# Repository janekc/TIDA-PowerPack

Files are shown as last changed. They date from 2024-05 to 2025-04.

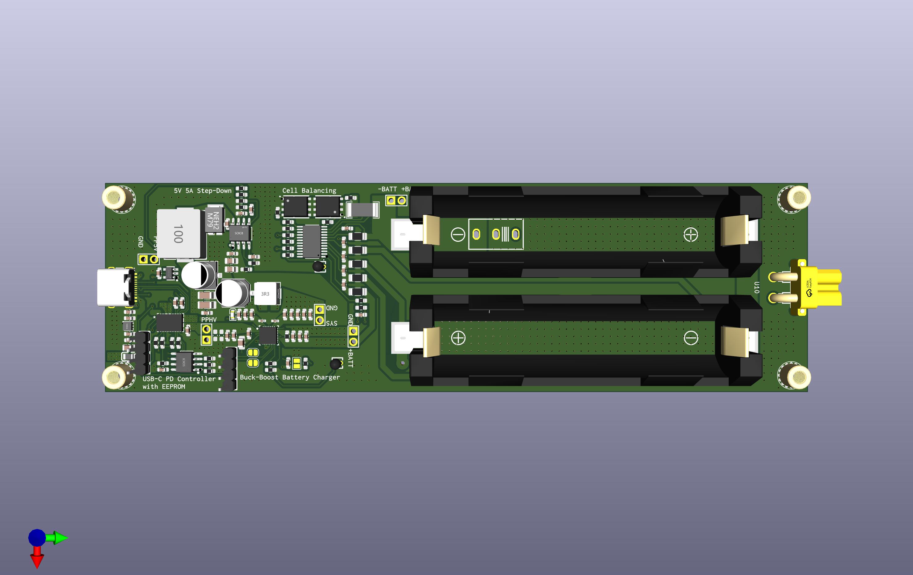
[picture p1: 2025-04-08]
TIDA-PowerPack.jpg

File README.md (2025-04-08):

# TIDA-PowerPack
This board is designed as a prototype for powering your projects using four 18650 lithium-ion battery cells. It delivers a 5V output with a maximum current of 5A. The cells are configured in a 4S1P (4-series, 1-parallel) arrangement, balanced and charged via USB-C Power Delivery (PD) with the maximum charging current supported by the cells.
This design is based on the [TIDA-050047](https://www.ti.com/tool/TIDA-050047#design-products) reference design by Texas Instruments.

TIDA-PowerPack

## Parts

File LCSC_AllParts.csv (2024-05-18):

LCSC Part Number | Manufacture Part Number | Manufacturer | Customer NO. | Package | Description | RoHS | Order Qty. | Min\Mult Order Qty. | Unit Price | Order Price | Type | Value | Rating
C2992604 | XT220UF10V90RV0073 | KNSCHA |  | SMD,D6.3xL5.4mm | 220uF 10V 95mA@120Hz ±20% SMD,D6.3xL5.4mm Aluminum Electrolytic Capacitors - SMD | YES | 40 | 20\20 | 0.039500 | 1.58 | Capacitor | 220uF | 10V
C597194 | 06035C104K4Z2A | Kyocera AVX |  | 0603 | 50V 100nF X7R ±10% 0603 Multilayer Ceramic Capacitors MLCC - SMD/SMT | YES | 250 | 50\50 | 0.020200 | 5.05 | Capacitor | 100nF(0.1uF) | 50V
C729457 | C0603X5R106K250NT | SANYEAR |  | 0603 | 25V 10uF ±10% 0603 Multilayer Ceramic Capacitors MLCC - SMD/SMT | YES | 100 | 10\10 | 0.060100 | 6.01 | Capacitor | 10uF | 25V
C1588 | CL10B102KB8NNNC | Samsung Electro-Mechanics |  | 0603 | 50V 1nF X7R ±10% 0603 Multilayer Ceramic Capacitors MLCC - SMD/SMT | YES | 400 | 100\100 | 0.003300 | 1.32 | Capacitor | 1nF | 50V
C2843785 | XL-5050RGBC-WS2812B | XINGLIGHT |  | SMD5050 | Positive post -30℃~+70℃ RGB 120° SMD5050 Light Emitting Diodes (LED) | YES | 180 | 10\10 | 0.052800 | 9.50 | Diode
C22962 | 0603WAF2200T5E | UNI-ROYAL(Uniroyal Elec) |  | 0603 | 100mW Thick Film Resistors ±100ppm/℃ ±1% 220Ω 0603 Chip Resistor - Surface Mount | YES | 400 | 100\100 | 0.001400 | 0.56 | Resistor | 220Ω | 100mW
C25804 | 0603WAF1002T5E | UNI-ROYAL(Uniroyal Elec) |  | 0603 | 100mW Thick Film Resistors ±100ppm/℃ ±1% 10000Ω 0603 Chip Resistor - Surface Mount | YES | 400 | 100\100 | 0.001100 | 0.44 | Resistor | 10kΩ | 100mW
C318893 | TS-1185EC-C-D-B | XKB Connectivity |  | SMD | No NO 50mA 100000 Times 260gf 12V Brick nogging SPST SMD Tactile Switches | YES | 40 | 10\10 | 0.059500 | 2.38 | Switch
C701341 | ESP32-WROOM-32E-N4 | Espressif Systems |  | SMD,18x25.5mm | SMD,18x25.5mm WiFi Modules | YES | 3 | 1\1 | 3.437100 | 10.31 | Microcontroller
C269429 | RMC0603621%N | TyoHM |  | 0603 | 100mW 1% 62Ω 0603 Chip Resistor - Surface Mount | YES | 100 | 50\50 | 0.004600 | 0.46 | Resistor | 62Ω | 100mW
C6568 | CP2102-GMR | SILICON LABS |  | WQFN-28-EP(5x5) | 1Mbps Transceiver USB WQFN-28-EP(5x5) USB ICs | YES | 3 | 1\1 | 2.737400 | 8.21 | IC
C319148 | U262-161N-4BVC11 | XKB Connectivity |  | SMD | 3A USB 3.1 1 260℃ Surface Mount 16P Female -40℃~+85℃ Gold Copper Alloy Type-C SMD USB Connectors | YES | 7 | 1\1 | 0.373300 | 2.61 | USB-C Port
C5400 | BL1117-33CX | BL(Shanghai Belling) |  | SOT-223 | 1A 60dB@(120Hz) Fixed 3.3V Positive 12V SOT-223 Linear Voltage Regulators (LDO) | YES | 30 | 10\10 | 0.089000 | 2.67 | IC
C62892 | UMH3N | Jiangsu Changjing Electronics Technology Co., Ltd. |  | SC-70-6(SOT-363) | 2 NPN - Pre-Biased 150mW 100mA 50V SC-70-6(SOT-363) Digital Transistors | YES | 60 | 10\10 | 0.052000 | 3.12 | Transistor
C507218 | SN74AHCT32QPWRQ1 | Texas Instruments |  | TSSOP-14 | 2uA 4.5V~5.5V 4 7.9ns@5V,50pF ORGate TSSOP-14 Gates | YES | 10 | 1\1 | 0.314800 | 3.15 | IC
C269696 | RMC06035.1K5%N | TyoHM |  | 0603 | 100mW 5% 5.1kΩ 0603 Chip Resistor - Surface Mount | YES | 300 | 100\100 | 0.002700 | 0.81 | Resistor | 5.1kΩ | 100mW
C2988620 | BH-18650-B1BA002 | MYOUNG |  | SMD | Battery case 18650 SMD Battery Connectors | YES | 8 | 1\1 | 1.431800 | 11.45 | Battery Case
C382139 | TP4056 | TPOWER |  | ESOP-8 | ESOP-8 Battery Management ICs | YES | 5 | 5\5 | 0.159700 | 0.80 | IC
C351410 | DW01A | PUOLOP |  | SOT-23-6L | SOT-23-6L Battery Management ICs | YES | 10 | 20\20 | 0.064600 | 0.65 | IC
C908265 | FS8205A | FUXINSEMI |  | SOT-23-6L | 20V 6A 18mΩ@4.5V,6A 1.5W 2 N-Channel SOT-23-6L MOSFETs | YES | 10 | 10\10 | 0.063800 | 0.64 | Transistor
C115325 | RS-03K1001FT | FH (Guangdong Fenghua Advanced Tech) |  | 0603 | 100mW ±100ppm/℃ ±1% 1kΩ 0603 Chip Resistor - Surface Mount | YES | 200 | 100\100 | 0.001200 | 0.24 | Resistor | 1kΩ | 100mW
C2889393 | 0603 ±5% 100Ω | VO |  | 0603 | 100mW Thick Film Resistors ±100ppm/℃ ±5% 100Ω 0603 Chip Resistor - Surface Mount | YES | 100 | 100\100 | 0.001800 | 0.18 | Resistor | 100Ω | 100mW
C269699 | RMC0603100K1%N | TyoHM |  | 0603 | 100mW 1% 100kΩ 0603 Chip Resistor - Surface Mount | YES | 100 | 100\100 | 0.003800 | 0.38 | Resistor | 100kΩ | 100mW
C19702 | CL10A106KP8NNNC | Samsung Electro-Mechanics |  | 0603 | 10V 10uF X5R ±10% 0603 Multilayer Ceramic Capacitors MLCC - SMD/SMT | YES | 50 | 100\100 | 0.007000 | 0.35 | Capacitor | 10uF | 10V
C72044 | 19-217/R6C-AL1M2VY/3T | Everlight Elec |  | 0603 | -40℃~+85℃ 617.5nm Red 120° 60mW 0603 Light Emitting Diodes (LED) | YES | 50 | 50\50 | 0.017400 | 0.87 | Diode
C193901 | NCD0603C2 | Foshan NationStar Optoelectronics |  | 0603 | Colorless transparence 17mcd~40mcd 565nm~578nm -30℃~+85℃ Green-yellow 130° 65mW 0603 Light Emitting Diodes (LED) | YES | 40 | 20\20 | 0.025500 | 1.02 | Diode
C269421 | RMC06032K1%N | TyoHM |  | 0603 | 100mW 1% 2kΩ 0603 Chip Resistor - Surface Mount | YES | 100 | 100\100 | 0.004100 | 0.41 | Resistor | 2kΩ | 100mW
C605444 | RU20P7C | INJOINIC |  | SOT-23-3L | SOT-23-3L MOSFETs | YES | 10 | 5\5 | 0.111700 | 1.12 | Transistor
C402889 | ERJ3EKF1133V | PANASONIC |  | 0603 | 100mW Thick Film Resistors ±100ppm/℃ ±1% 113000Ω 0603 Chip Resistor - Surface Mount | YES | 50 | 50\50 | 0.006100 | 0.31 | Resistor | 113kΩ | 100mW
C2847559 | MDA1050-2R2M | KOHERelec |  | SMD,10x11mm | 19.5A 2.2uH ±20% 20A 5.1mΩ SMD,10x11mm Inductors (SMD) | YES | 7 | 1\1 | 0.975300 | 6.83 | Coil | 2.2uH | 19.5A
C525386 | TCTR0805F100KF4000T | RESI |  | 0805 | 100kΩ 130mW ±1% 4000K ±1% 0805 NTC Thermistors | YES | 20 | 5\5 | 0.113900 | 2.28 | Resistor | 100kΩ | 130mW
C5139726 | RAT038202FTP | RALEC |  | 0603 | ±1% 82kΩ 0603 Chip Resistor - Surface Mount | YES | 50 | 50\50 | 0.002500 | 0.13 | Resistor | 82kΩ | 100mW
C2915632 | SMTSO3015CTJ | Sinhoo |  | - | - SMD round nut | YES | 50 | 5\5 | 0.050400 | 2.52 | SMD Nut
C123705 | CS1E102M-CRI13 | ST(Semtech) |  | SMD,D12.5xL13.5mm | 1000uF 25V ±20% SMD,D12.5xL13.5mm Aluminum Electrolytic Capacitors - SMD | YES | 10 | 1\1 | 0.202100 | 2.02 | Capacitor | 1000uF | 25V
C5301865 | BSMD1812-350-16V | BHFUSE |  | 1812 | 16V 3.5A 100A 7A 1812 Resettable Fuses | YES | 25 | 5\5 | 0.109000 | 2.73 | Fuse | 3.5A | 16V
C1730607 | PE0603FRF570R01L | YAGEO |  | 0603 | 500mW ±100ppm/℃ ±1% 10mΩ 0603 Chip Resistor - Surface Mount | YES | 10 | 5\5 | 0.156400 | 1.56 | Resistor | 10mΩ | 500mW
C23630 | CL10A225KO8NNNC | Samsung Electro-Mechanics |  | 0603 | 16V 2.2uF X5R ±10% 0603 Multilayer Ceramic Capacitors MLCC - SMD/SMT | YES | 50 | 100\100 | 0.007400 | 0.37 | Capacitor | 2.2uF | 16V
C3017715 | SCR0603J10K | VO |  | 0603 | ±5% 10kΩ 0603 Chip Resistor - Surface Mount | YES | 100 | 100\100 | 0.000800 | 0.08 | Resistor | 10kΩ | 100mW
C404969 | MicroXNJ | SHOU HAN |  | SMD | 1A USB 2.0 1 Surface Mount 5P Female -20℃~+85℃ Micro-B SMD USB Connectors | YES | 10 | 10\10 | 0.033800 | 0.34 | MicroUSB Port
C2897410 | PM254-2-09-Z-8.5 | HCTL |  | Plugin,P=2.54mm | 2.54mm 2.54mm 3A 18P -40℃~+105℃ Straight 2x9P 8.5mm Top Square Holes Plugin,P=2.54mm Female Headers | YES | 24 | 6\6 | 0.244800 | 5.88 | Pin Header
C142682 | 0287005.PXCN | Littelfuse |  | - | Fast Blow 32V 1kA Fuse Automotive Holder Blade 5A - Automotive Fuses | YES | 20 | 5\5 | 0.075600 | 1.51 | Fuse | 5A | 32V
C142683 | 0287010.PXCN | Littelfuse |  | - | Fast Blow 32V 1kA Fuse Automotive Holder Blade 10A - Automotive Fuses | YES | 5 | 5\5 | 0.069900 | 0.35 | Fuse | 10A | 32V
C223811 | K2-1112SW-A4SW-04 | Korean Hroparts Elec |  | SMD | 50mA Lying SPST 100MΩ 100000 Times 250gf@±30gf 12V SMD Tactile Switches | YES | 30 | 10\10 | 0.064800 | 1.94 | Switch
C123946 | SS54 | Shandong Jingdao Microelectronics |  | SMA(DO-214AC) | 40V 550mV@5A 5A SMA(DO-214AC) Schottky Barrier Diodes (SBD) | YES | 10 | 10\10 | 0.037800 | 0.38 | Diode
C3017686 | SCR0603J160K | VO |  | 0603 | ±5% 160kΩ 0603 Chip Resistor - Surface Mount | YES | 100 | 100\100 | 0.000800 | 0.08 | Resistor | 160kΩ | 100mW
C2886385 | AP40P05 | ALLPOWER(ShenZhen Quan Li Semiconductor) |  | SOT-23 | 40V 5A 65mΩ@10V,3A 2W P Channel SOT-23 MOSFETs | YES | 20 | 10\10 | 0.057700 | 1.15 | Transistor
C269681 | RMC06031.2K5%N | TyoHM |  | 0603 | 100mW 5% 1.2kΩ 0603 Chip Resistor - Surface Mount | YES | 100 | 100\100 | 0.002400 | 0.24 | Resistor | 1.2kΩ | 100mW
C88716 | TPS61032PWPR | Texas Instruments |  | HTSSOP-16-EP | boost converterType Fixed 5V 1.8V~5.5V 3.6A HTSSOP-16-EP DC-DC Converters | YES | 5 | 1\1 | 1.540100 | 7.70 | IC
C177249 | FXL0530-6R8-M | cjiang (Changjiang Microelectronics Tech) |  | SMD,5.2x5.4mm | 3.5A 6.8uH Molding Choke ±20% 4A SMD,5.2x5.4mm Power Inductors | YES | 10 | 5\5 | 0.129400 | 1.29 | Coil | 6.8uH | 3.5A
C2688664 | MP34DT05TR-A | STMicroelectronics |  | HCLGA-5(3x4) | Omnidirectional -26dB 64dB HCLGA-5(3x4) MEMS Microphones | YES | 5 | 1\1 | 1.546400 | 7.73 | Microphone
C15849 | CL10A105KB8NNNC | Samsung Electro-Mechanics |  | 0603 | 50V 1uF X5R ±10% 0603 Multilayer Ceramic Capacitors MLCC - SMD/SMT | YES | 100 | 100\100 | 0.005700 | 0.57 | Capacitor | 1uF | 50V
C128413 | SN74LVC1G373DBVR | Texas Instruments |  | SOT-23-6 | 1.65V~5.5V D-Typelocking Latch 1ns SOT-23-6 Latches | YES | 5 | 5\5 | 0.203000 | 1.02 | IC
C45783 | CL21A226MAQNNNE | Samsung Electro-Mechanics |  | 0805 | 25V 22uF X5R ±20% 0805 Multilayer Ceramic Capacitors MLCC - SMD/SMT | YES | 40 | 20\20 | 0.026300 | 1.05 | Capacitor | 22uF | 25V
C2879839 | SS-12M11G5 | XKB Connectivity |  | Plugin | Straight 6A SPDT 120V 120V 6A 10000次 Black Plugin Slide Switches | YES | 10 | 5\5 | 0.339400 | 3.39 | Switch
C8413 | WJ15EDGK-3.81-3P | Ningbo Kangnex Elec |  | P=3.81mm | 3 1 3.81mm 1x3P Green Plug P=3.81mm Pluggable System Terminal Block | YES | 30 | 5\5 | 0.181400 | 5.44 | Terminal Block
C8406 | WJ15EDGRC-3.81-3P | Ningbo Kangnex Elec |  | Push-Pull,P=3.81mm | 3 Bend 1 3.81mm 1x3P Green Board Edge/Receptacle-Close Push-Pull,P=3.81mm Pluggable System Terminal Block | YES | 30 | 10\10 | 0.036800 | 1.10 | Terminal Block
C910846 | BSMD2920-500-16V | BHFUSE |  | 2920 | 16V 5A 40A 10A 2920 Resettable Fuses | YES | 30 | 5\5 | 0.168900 | 5.07 | Fuse | 5A | 16V
C18164540 | BSMD1812-400-12V | BHFUSE |  | 1812 | 12V 4A 100A 8A 1812 Resettable Fuses | YES | 10 | 5\5 | 0.124500 | 1.25 | Fuse | 4A | 16V
C2935469 | XF-508P-A | XFCN |  | Plugin | Plugin Fuse Holders | YES | 10 | 5\5 | 0.239600 | 2.40 | Fuse Holder
C81010 | CH340B | WCH(Jiangsu Qin Heng) |  | SOIC-16 | 2Mbps Transceiver USB 2.0 SOIC-16 USB ICs | YES | 2 | 1\1 | 0.889400 | 1.78 | IC
C142683 | 0287010.PXCN | Littelfuse |  | - | Fast Blow 32V 1kA Fuse Automotive Holder Blade 10A - Automotive Fuses | YES | 30 | 5\5 | 0.083900 | 2.52 | Fuse Holder
C18195411 | 1N4148 | LangJie |  | DO-35 | DO-35 Switching Diode | YES | 50 | 50\50 | 0.010700 | 0.54 | Diode
C585171 | TS-1010-A3B3-D2 | Yuandi |  | Plugin,6.2x6.2mm | Plugin,6.2x6.2mm Tactile Switches | YES | 5 | 5\5 | 0.101500 | 0.51 | Switch

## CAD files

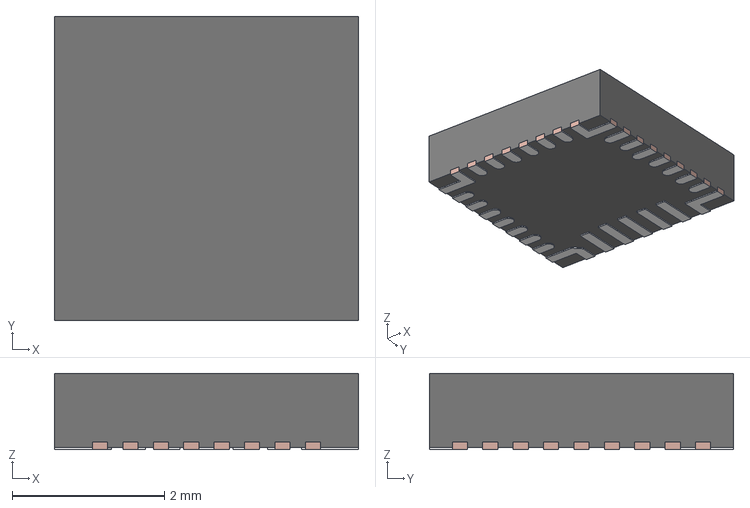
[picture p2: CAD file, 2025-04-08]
ul_BQ25798RQMR/RQM0029A.stp
4.00 x 4.00 x 1.00 mm
FRAME
MOLD

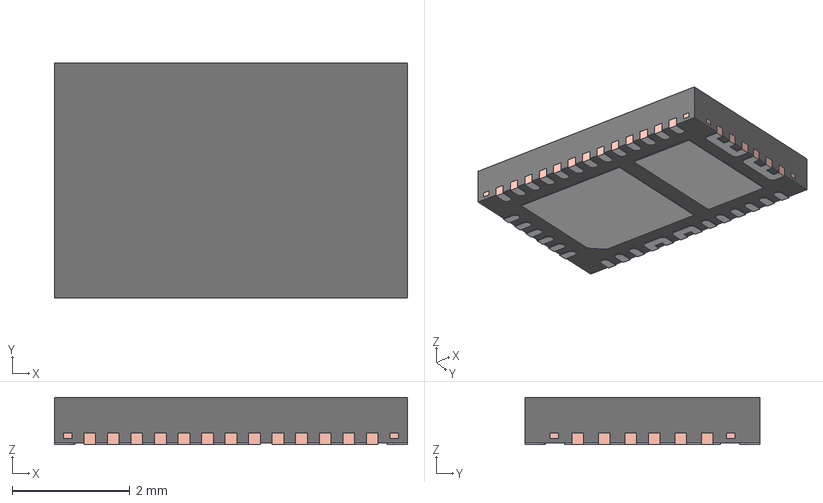
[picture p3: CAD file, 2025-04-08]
ul_PTPS25751DREFR/REF0038A.stp
6.00 x 4.00 x 0.8 mm
BODY-QFN
FRAME-REF0038A
PIN1-ID

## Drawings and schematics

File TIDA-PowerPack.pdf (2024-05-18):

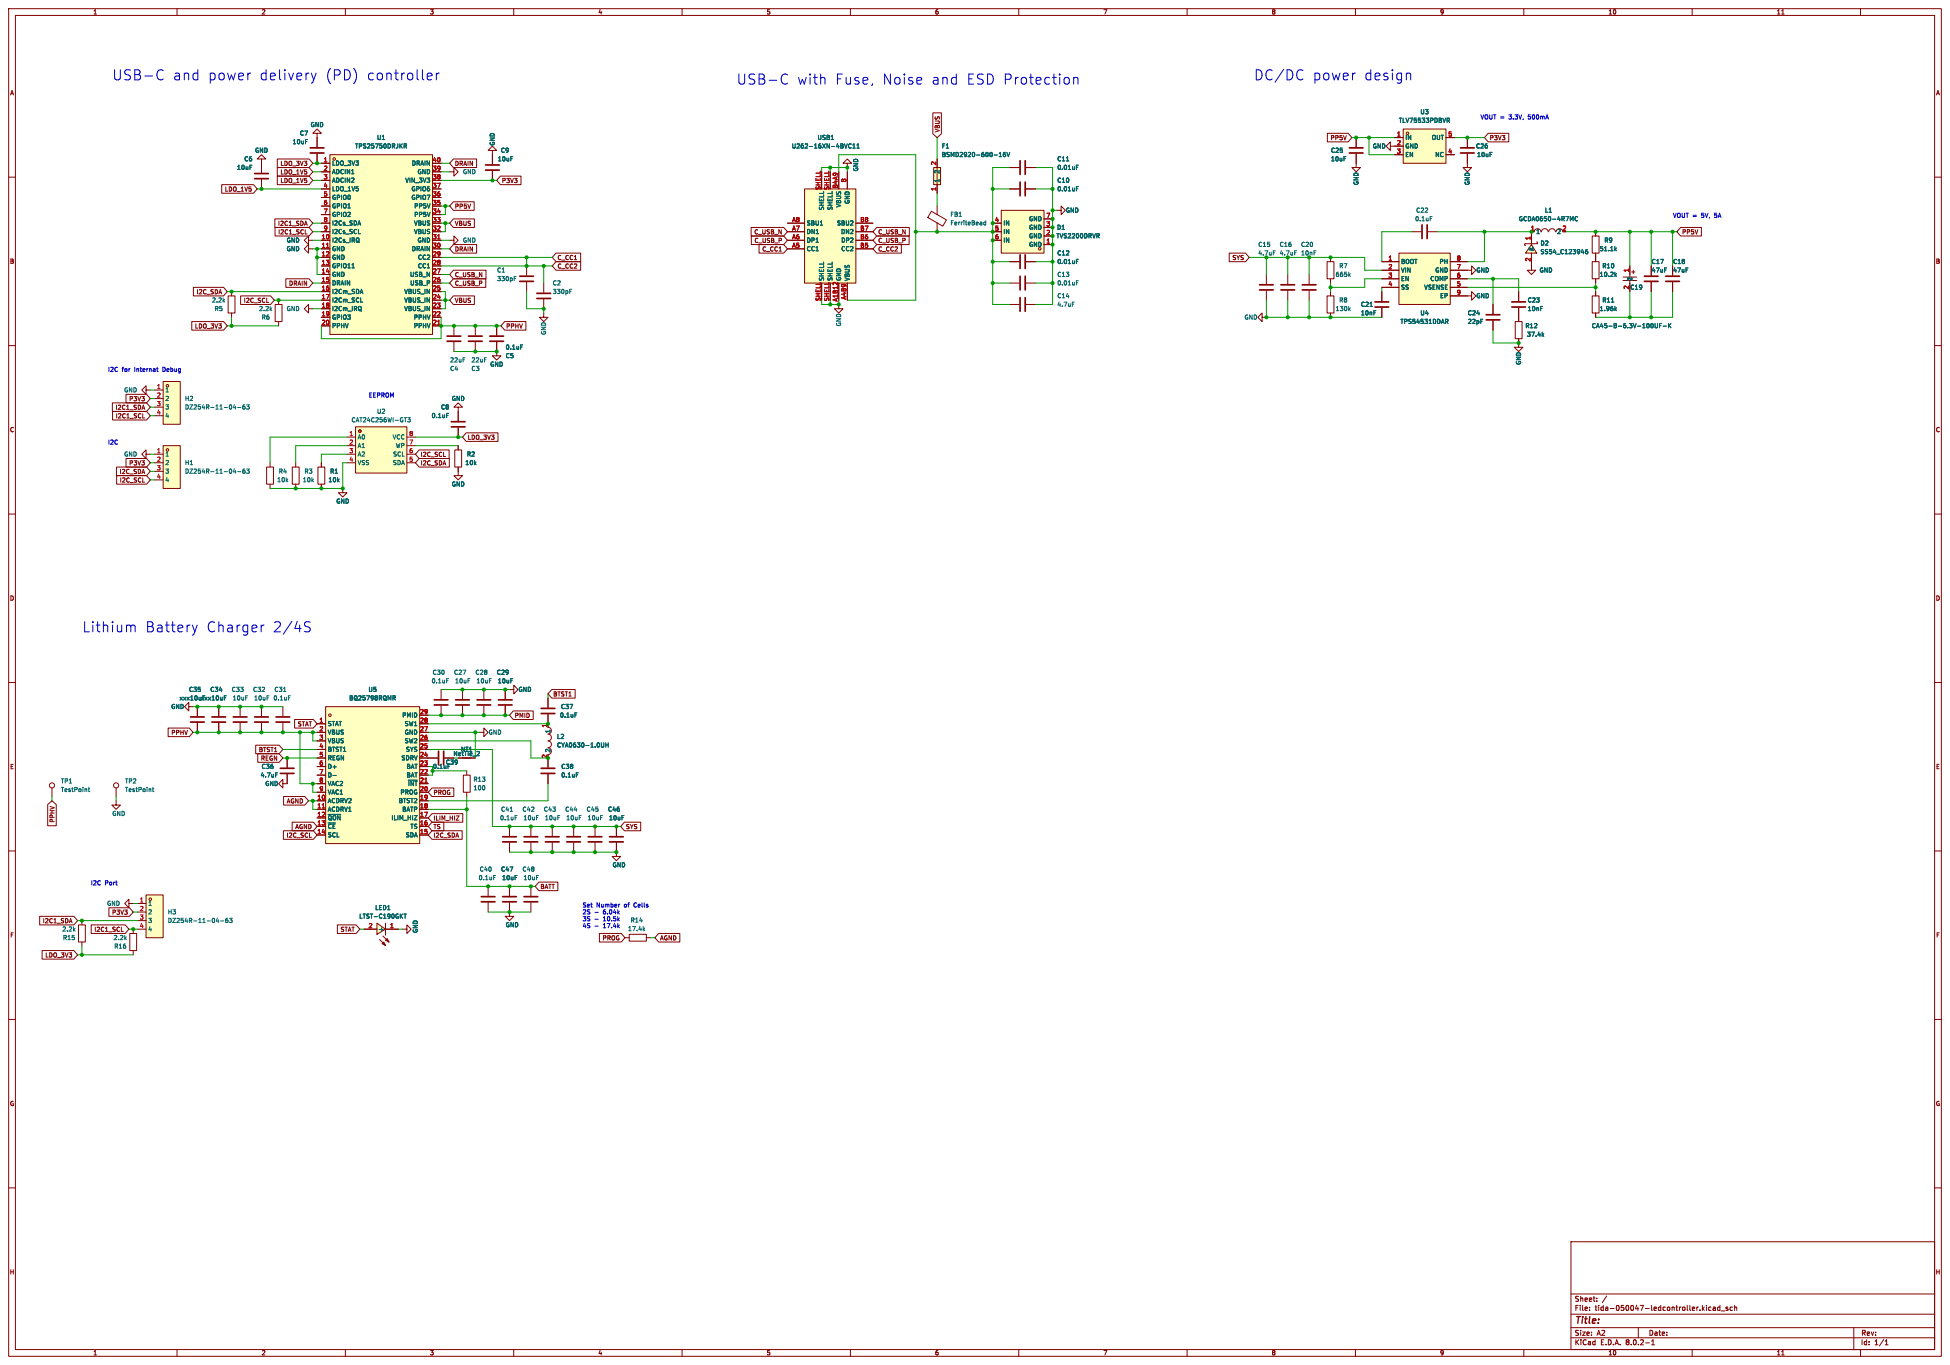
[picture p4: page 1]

USB-C and power delivery (PD) controller

8 GND A1B12 VBUS A4B9 CC1 A5 DP1 A6 DN1 A7 SBU1 A8 VBUS B4A9 CC2 B5 DP2 B6 DN2 B7 SBU2 B8 SHELL SHELL SHELL SHELL SHELL SHELL SHELL SHELL USB1 U262-16XN-4BVC11 GND

8 GND A1B12 VBUS A4B9 CC1 A5 DP1 A6 DN1 A7 SBU1 A8 VBUS B4A9 CC2 B5 DP2 B6 DN2 B7 SBU2 B8 SHELL SHELL SHELL SHELL SHELL SHELL SHELL SHELLGND

I2Cs_IRQ 10 GND 11 GND 12 GPIO11 13 GND 14 DRAIN 15

Set Number of Cells 2S - 6.04k 3S - 10.5k 4S - 17.4k

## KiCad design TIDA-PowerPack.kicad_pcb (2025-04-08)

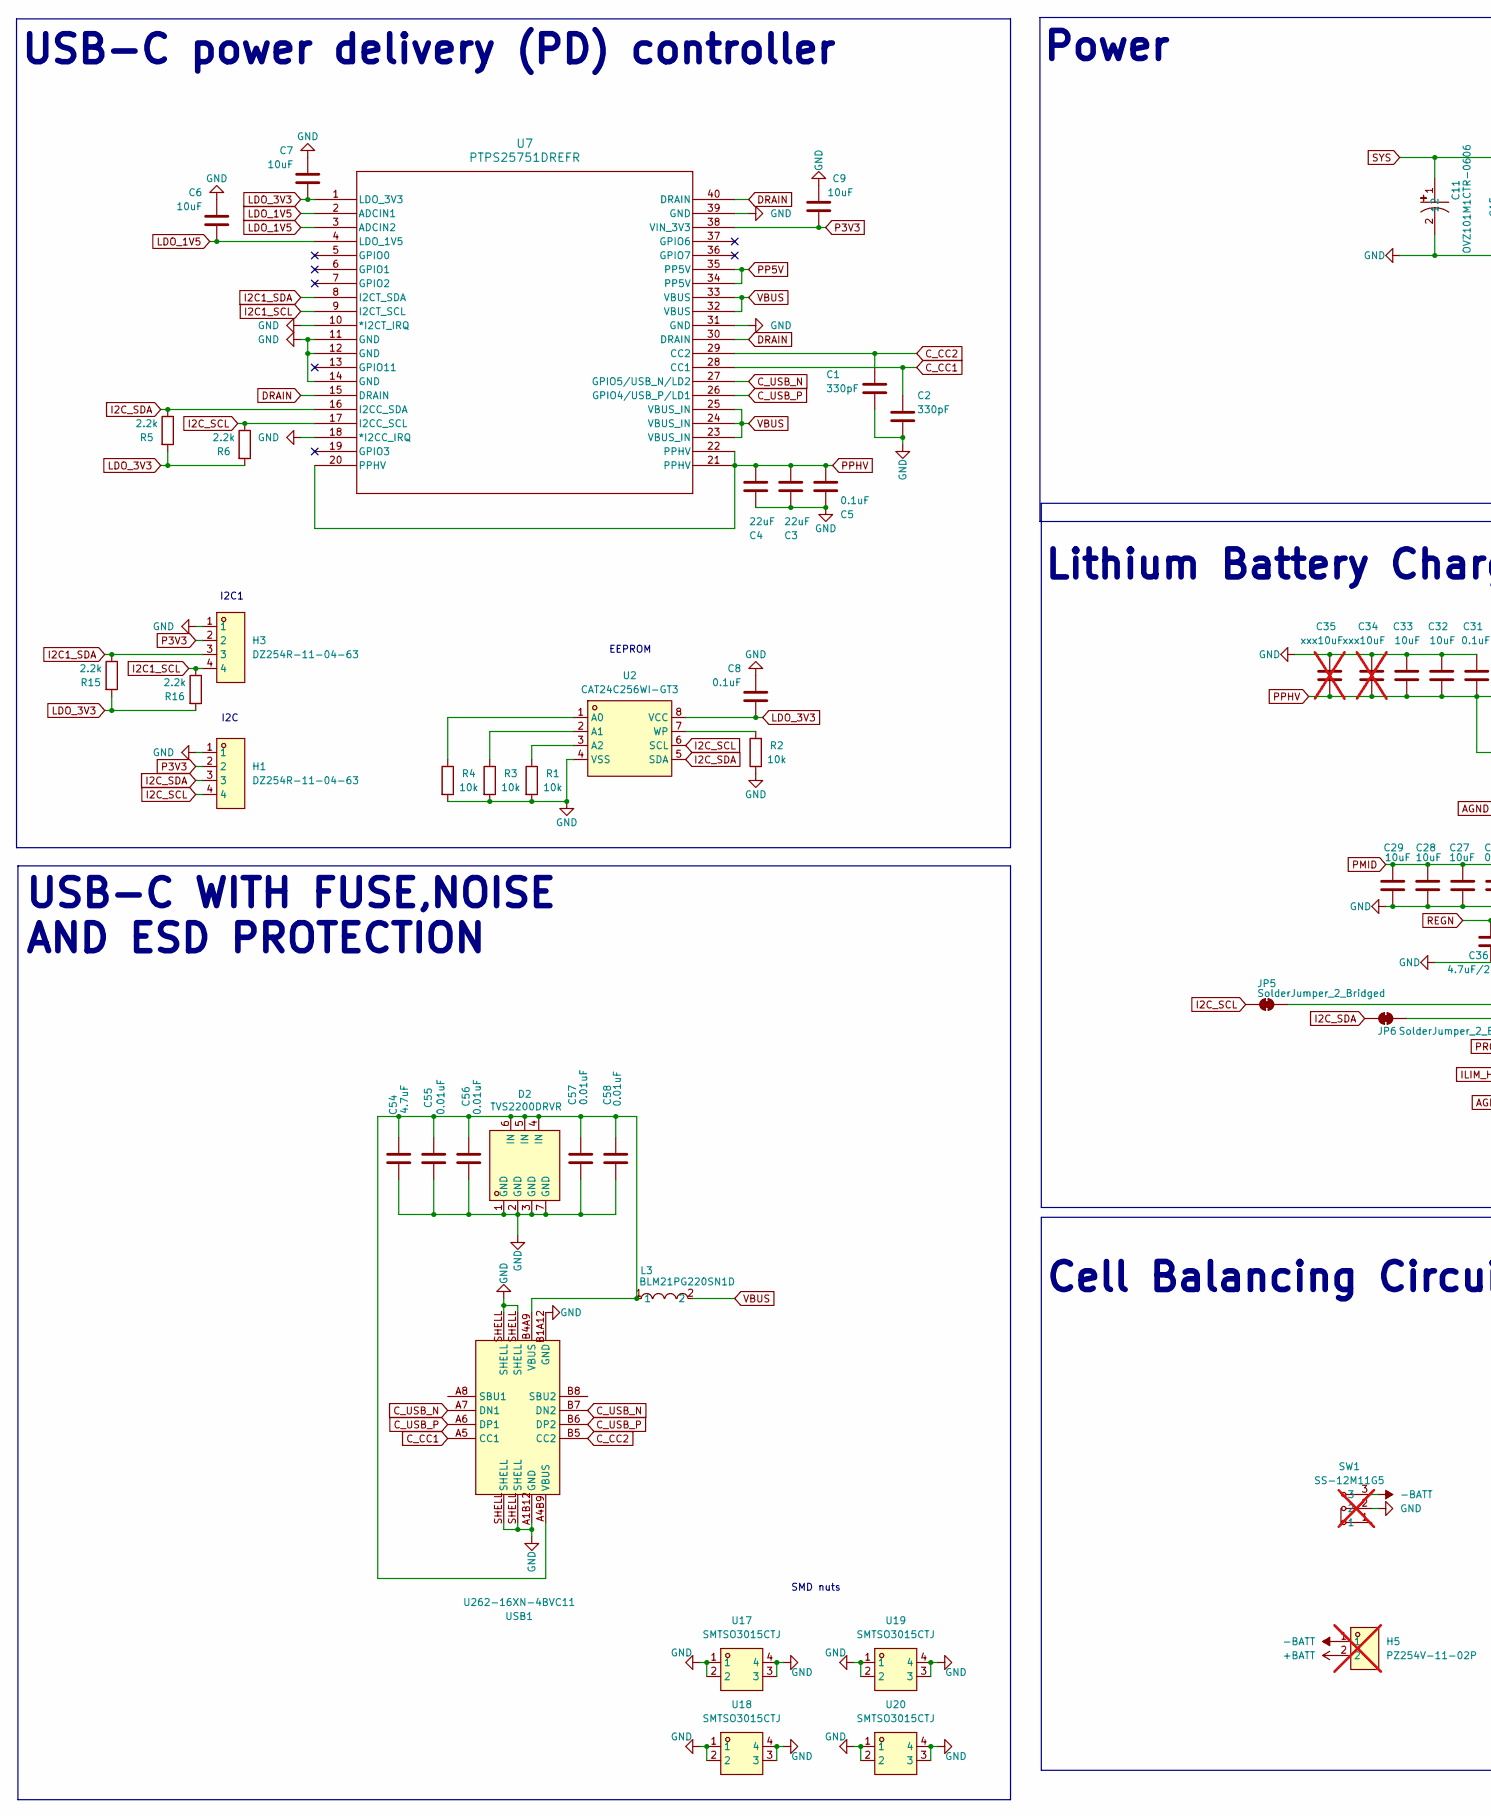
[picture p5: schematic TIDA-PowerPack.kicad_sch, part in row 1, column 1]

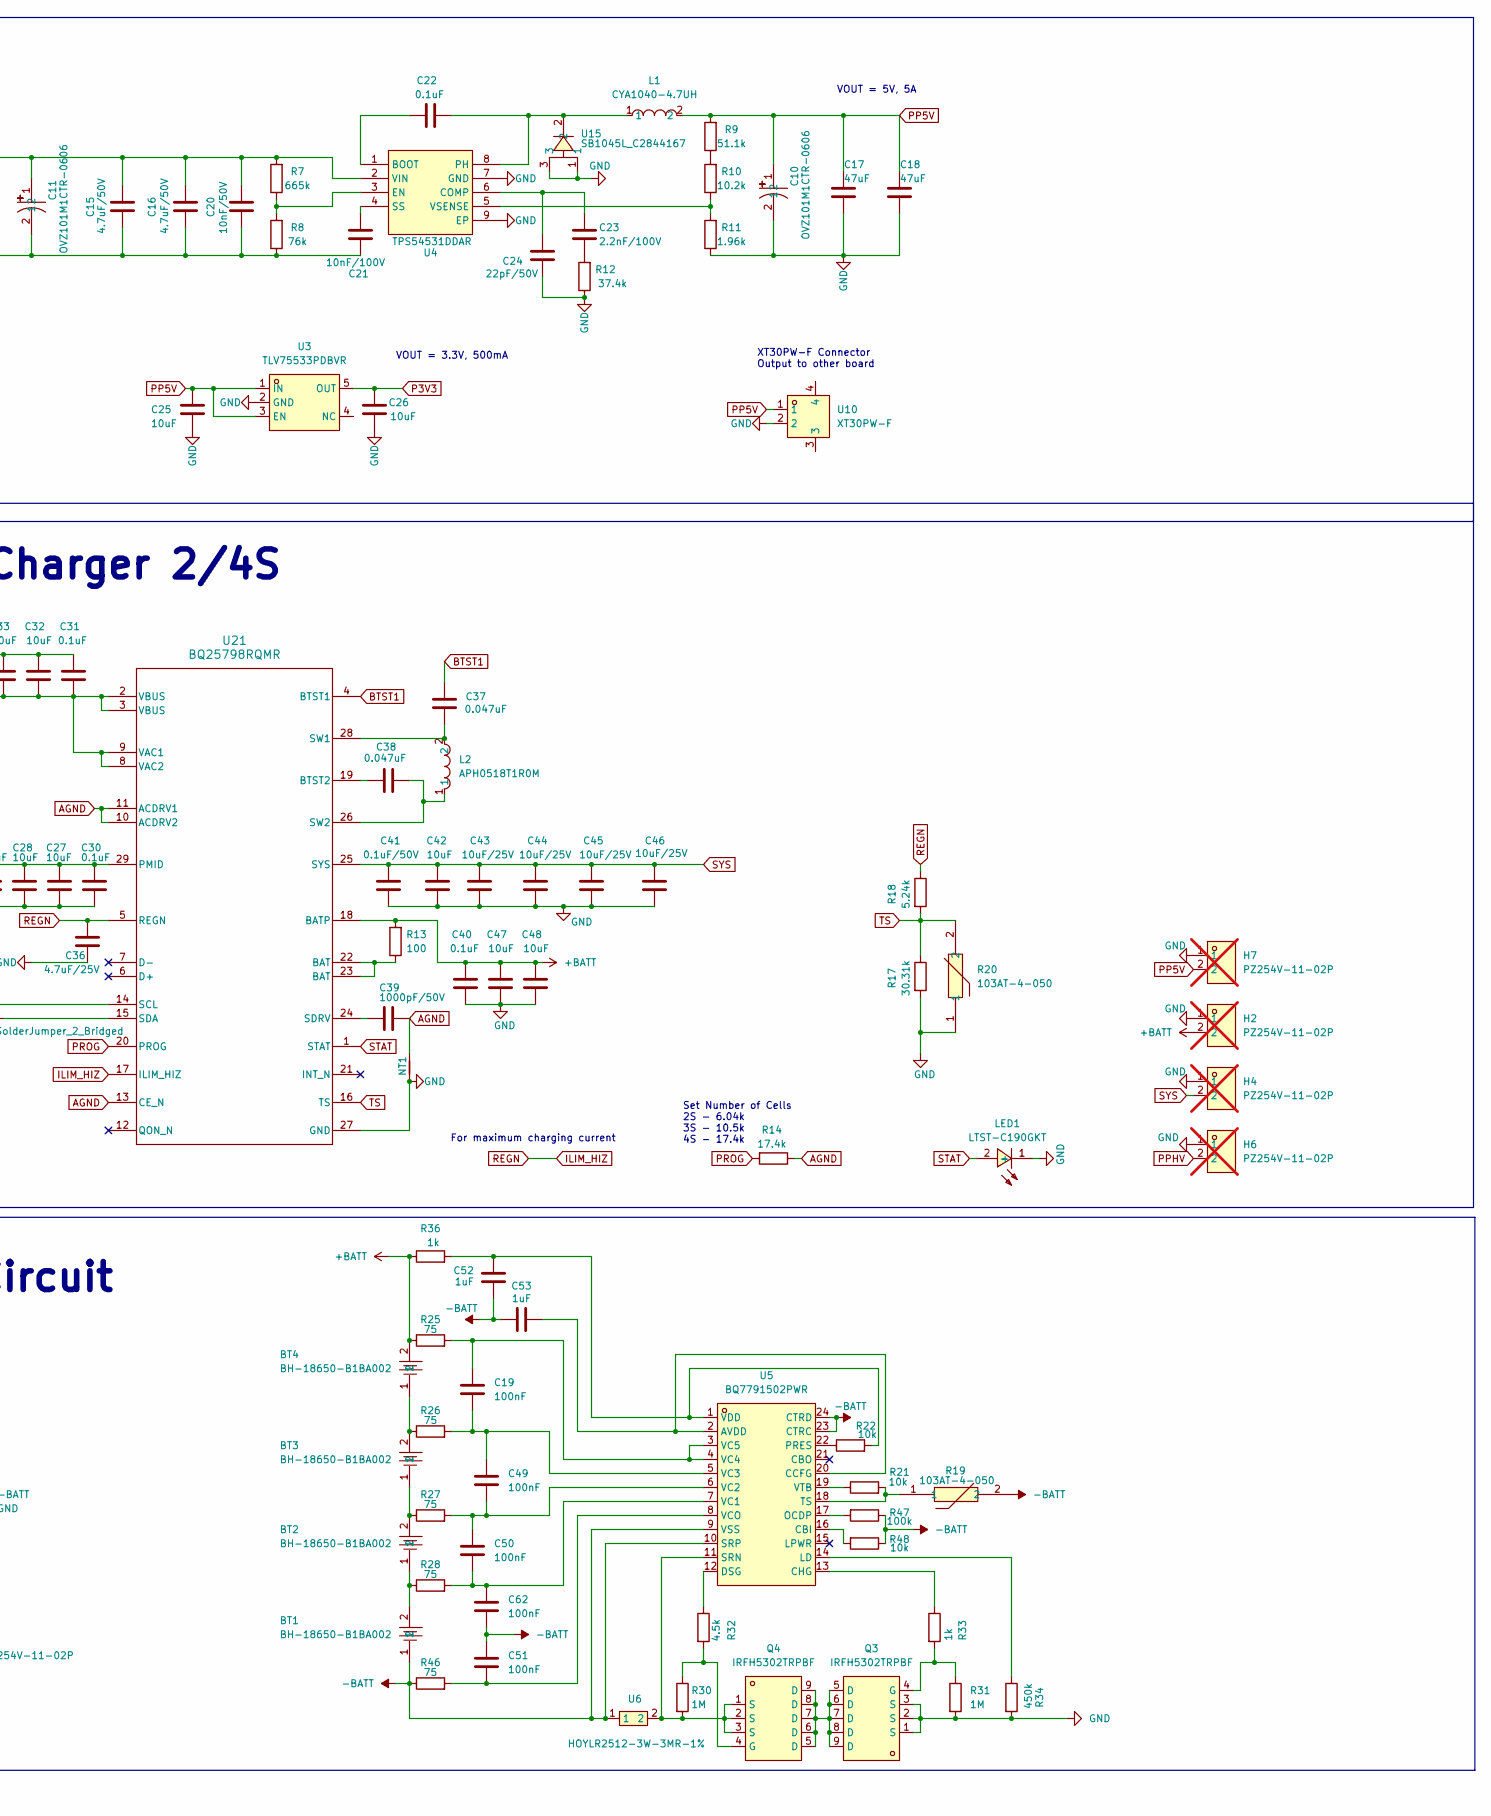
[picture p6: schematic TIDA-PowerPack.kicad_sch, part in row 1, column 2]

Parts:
BT1, BT2, BT3, BT4: BH-18650-B1BA002; BATTERY-SMD_18650-1S-L77.1-W20.7-1; LCSC Part C2988620
C1, C2: 330pF; C_0603_1608Metric_Pad1.08x0.95mm_HandSolder
C3, C4: 22uF; C_0805_2012Metric_Pad1.18x1.45mm_HandSolder
C5, C8, C22, C31, C40: 0.1uF; C_0603_1608Metric_Pad1.08x0.95mm_HandSolder
C6, C7, C9, C25, C26, C27, C28, C29, C32, C33, C42, C47, C48: 10uF; C_0603_1608Metric_Pad1.08x0.95mm_HandSolder
C10, C11: OVZ101M1CTR-0606; CAP-SMD_BD6.3-L6.6-W6.6-FD-A; LCSC Part C134878
C15, C16: 4.7uF/50V; C_0805_2012Metric_Pad1.18x1.45mm_HandSolder; LCSC Part C2991173
C17, C18: 47uF; C_1206_3216Metric_Pad1.33x1.80mm_HandSolder; LCSC Part C7472975
C19, C49, C50, C51, C62: 100nF; C_0603_1608Metric_Pad1.08x0.95mm_HandSolder
C20: 10nF/50V; C_0603_1608Metric_Pad1.08x0.95mm_HandSolder
C21: 10nF/100V; C_0603_1608Metric_Pad1.08x0.95mm_HandSolder
C23: 2.2nF/100V; C_0603_1608Metric_Pad1.08x0.95mm_HandSolder
C24: 22pF/50V; C_0603_1608Metric_Pad1.08x0.95mm_HandSolder
C30: 0.1uF; C_0402_1005Metric_Pad0.74x0.62mm_HandSolder
C34, C35: xxx10uF; C_0603_1608Metric_Pad1.08x0.95mm_HandSolder; not fitted
C36: 4.7uF/25V; C_0805_2012Metric_Pad1.18x1.45mm_HandSolder; LCSC Part C2991173
C37, C38: 0.047uF; C_0603_1608Metric_Pad1.08x0.95mm_HandSolder
C39: 1000pF/50V; C_0603_1608Metric_Pad1.08x0.95mm_HandSolder
C41: 0.1uF/50V; C_0402_1005Metric_Pad0.74x0.62mm_HandSolder
C43, C44, C45, C46: 10uF/25V; C_0603_1608Metric_Pad1.08x0.95mm_HandSolder
C52: 1uF; R_0603_1608Metric_Pad0.98x0.95mm_HandSolder
C53: 1uF; C_0603_1608Metric_Pad1.08x0.95mm_HandSolder
C54: 4.7uF; C_0805_2012Metric_Pad1.18x1.45mm_HandSolder
C55, C56, C57, C58: 0.01uF; C_0603_1608Metric_Pad1.08x0.95mm_HandSolder
D2: TVS2200DRVR; WSON-6_L2.0-W2.0-P0.65-BL-EP; LCSC Part C523793
H1, H3: DZ254R-11-04-63; HDR-TH_4P-P2.54-V-M; LCSC Part C2935910
H2, H4, H5, H6, H7: PZ254V-11-02P; HDR-TH_2P-P2.54-V-M; LCSC Part C492401; not fitted
JP5, JP6: SolderJumper_2_Bridged; SolderJumper-2_P1.3mm_Bridged_RoundedPad1.0x1.5mm
L1: CYA1040-4.7UH; IND-SMD_L11.6-W10.1; LCSC Part C6364675
L2: APH0518T1R0M; IND-SMD_L5.4-W5.2; LCSC Part C5349672
L3: BLM21PG220SN1D; L0805; LCSC Part C88993
LED1: LTST-C190GKT; LED0603-RD; LCSC Part C125093
NT1: NetTie_2; SolderJumper-2_P1.3mm_Bridged2Bar_Pad1.0x1.5mm
Q3, Q4: IRFH5302TRPBF; PQFN-8_L6.0-W5.0-P1.27-LS6.0-BL; LCSC Part C148153
R1, R2, R3, R4, R21, R22, R48: 10k; R_0603_1608Metric_Pad0.98x0.95mm_HandSolder
R5, R6, R15, R16: 2.2k; R_0603_1608Metric_Pad0.98x0.95mm_HandSolder
R7: 665k; R_0603_1608Metric_Pad0.98x0.95mm_HandSolder; LCSC Part C407512
R8: 76k; R_0603_1608Metric_Pad0.98x0.95mm_HandSolder; LCSC Part C269519
R9: 51.1k; R_0603_1608Metric_Pad0.98x0.95mm_HandSolder; LCSC Part C407512
R10: 10.2k; R_0603_1608Metric_Pad0.98x0.95mm_HandSolder; LCSC Part C407512
R11: 1.96k; R_0603_1608Metric_Pad0.98x0.95mm_HandSolder; LCSC Part C407512
R12: 37.4k; R_0603_1608Metric_Pad0.98x0.95mm_HandSolder; LCSC Part C269519
R13: 100; R_0603_1608Metric_Pad0.98x0.95mm_HandSolder; LCSC Part C407512
R14: 17.4k; R_0603_1608Metric_Pad0.98x0.95mm_HandSolder; LCSC Part C407512
R17: 30.31k; R_0603_1608Metric_Pad0.98x0.95mm_HandSolder; LCSC Part C407512
R18: 5.24k; R_0603_1608Metric_Pad0.98x0.95mm_HandSolder; LCSC Part C407512
R19, R20: 103AT-4-050; RES-TH_L2.5-W2.5-P1.70-D0.3; LCSC Part C497233
R25, R26, R27, R28, R46: 75; R_1206_3216Metric_Pad1.30x1.75mm_HandSolder
R30, R31: 1M; R_0603_1608Metric_Pad0.98x0.95mm_HandSolder
R32: 4.5k; R_0603_1608Metric_Pad0.98x0.95mm_HandSolder
R33, R36: 1k; R_0603_1608Metric_Pad0.98x0.95mm_HandSolder
R34: 450k; R_0603_1608Metric_Pad0.98x0.95mm_HandSolder
R47: 100k; R_0603_1608Metric_Pad0.98x0.95mm_HandSolder
SW1: SS-12M11G5; SW-TH_XKB_SS-12M11XX; LCSC Part C2879839; not fitted
U2: CAT24C256WI-GT3; SOIC-8_L4.9-W3.9-P1.27-LS6.0-BL; LCSC Part C79987
U3: TLV75533PDBVR; SOT-23-5_L3.0-W1.7-P0.95-LS2.8-BR; LCSC Part C404027
U4: TPS54531DDAR; SOIC-8_L5.0-W4.0-P1.27-LS6.0-BL-EP2.0; LCSC Part C50605
U5: BQ7791502PWR; TSSOP-24_L7.8-W4.4-P0.65-LS6.4-BL_1; LCSC Part C2865574
U6: HOYLR2512-3W-3MR-1%; R2512; LCSC Part C5375459
U7: PTPS25751DREFR; WQFN38_REF_TEX
U10: XT30PW-F; CONN-TH_XT30PW-F-1; LCSC Part C2913282
U15: SB1045L_C2844167; TO-277_3P-L5.4-W4.0-LS6.5-TR; LCSC Part C2844167
U17, U18, U19, U20: SMTSO3015CTJ; SMTSO3030CTJ; LCSC Part C2915632
U21: BQ25798RQMR; RQM0029A-MFG
USB1: U262-16XN-4BVC11; USB-3.1-SMD_U262-161N-4BVC11; LCSC Part C319148

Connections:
+BATT: BT4.2, C40.2, C47.2, C48.2, H2.2, H5.2, R13.2, R25.1, R36.1, U21.18 (BATP)
-BATT: BT1.1, C51.1, C52.1, C53.1, C62.2, H5.1, R19.2, R46.1, R47.1, R48.1, SW1.3, U5.9 (VSS), U5.10 (SRP), U5.23 (CTRC), U5.24 (CTRD), U6.1
AGND: C39.1, NT1.1, R14.1, U21.10 (ACDRV2), U21.11 (ACDRV1), U21.13 (CE_N)
BTST1: C37.2, U21.4 (BTST1)
C_CC1: C2.1, U7.28 (CC1), USB1.A5 (CC1)
C_CC2: C1.1, U7.29 (CC2), USB1.B5 (CC2)
C_USB_N: U7.27 (GPIO5/USB_N/LD2), USB1.A7 (DN1), USB1.B7 (DN2)
C_USB_P: U7.26 (GPIO4/USB_P/LD1), USB1.A6 (DP1), USB1.B6 (DP2)
DRAIN: U7.15 (DRAIN), U7.30 (DRAIN), U7.40 (DRAIN)
GND: C1.2, C2.2, C3.2, C4.2, C5.2, C6.2, C7.2, C8.2, C9.2, C10.2, C11.2, C15.2, C16.2, C17.2, C18.2, C20.2, C21.2, C24.2, C25.2, C26.1, C27.2, C28.2, C29.2, C30.2, C31.2, C32.2, C33.2, C34.2, C35.2, C36.1, C40.1, C41.1, C42.1, C43.1, C44.1, C45.1, C46.1, C47.1, C48.1, C54.1, C55.1, C56.1, C57.1, C58.1, D2.1 (GND), D2.2 (GND), D2.3 (GND), D2.7 (GND), H1.1, H2.1, H3.1, H4.1, H6.1, H7.1, LED1.1 (-), NT1.2, Q3.1 (S), Q3.2 (S), Q3.3 (S), R1.2, R2.1, R3.2, R4.2, R8.1, R11.1, R12.1, R17.2, R20.1, R31.2, R34.2, SW1.2, U2.4 (VSS), U3.2 (GND), U4.7 (GND), U4.9 (EP), U7.10 (*I2CT_IRQ), U7.11 (GND), U7.12 (GND), U7.14 (GND), U7.18 (*I2CC_IRQ), U7.31 (GND), U7.39 (GND), U10.2, U15.1, U15.3, U17.1, U17.2, U17.3, U17.4, U18.1, U18.2, U18.3, U18.4, U19.1, U19.2, U19.3, U19.4, U20.1, U20.2, U20.3, U20.4, U21.27 (GND), USB1.A1B12 (GND), USB1.B1A12 (GND), USB1.SHELL
I2C1_SCL: H3.4, R16.1, U7.9 (I2CT_SCL)
I2C1_SDA: H3.3, R15.1, U7.8 (I2CT_SDA)
I2C_SCL: H1.4, JP5.1 (A), R6.1, U2.6 (SCL), U7.17 (I2CC_SCL)
I2C_SDA: H1.3, JP6.1 (A), R5.1, U2.5 (SDA), U7.16 (I2CC_SDA)
ILIM_HIZ: C36.2, R18.1, U21.5 (REGN), U21.17 (ILIM_HIZ)
LDO_1V5: C6.1, U7.2 (ADCIN1), U7.3 (ADCIN2), U7.4 (LDO_1V5)
LDO_3V3: C7.1, C8.1, R5.2, R6.2, R15.2, R16.2, U2.8 (VCC), U7.1 (LDO_3V3)
unnamed: BT1.2, BT2.1, R28.1
unnamed: BT2.2, BT3.1, R27.1
unnamed: BT3.2, BT4.1, R26.1
unnamed: C23.2, R12.2
unnamed: C54.2, C55.2, C56.2, C57.2, C58.2, D2.4 (IN), D2.5 (IN), D2.6 (IN), L3.1, USB1.A4B9 (VBUS), USB1.B4A9 (VBUS)
unnamed: JP5.2 (B), U21.14 (SCL)
unnamed: JP6.2 (B), U21.15 (SDA)
unnamed: Q3.5 (D), Q3.6 (D), Q3.7 (D), Q3.8 (D), Q3.9 (D), Q4.5 (D), Q4.6 (D), Q4.7 (D), Q4.8 (D), Q4.9 (D)
unnamed: Q3.4 (G), R31.1, R33.2
unnamed: Q4.4 (G), R30.1, R32.2
unnamed: R9.1, R10.2
unnamed: R13.1, U21.22 (BAT), U21.23 (BAT)
unnamed: R4.1, U2.1 (A0)
unnamed: R3.1, U2.2 (A1)
unnamed: R1.1, U2.3 (A2)
unnamed: R2.2, U2.7 (WP)
unnamed: C22.1, U4.1 (BOOT)
unnamed: C23.1, C24.1, U4.6 (COMP)
unnamed: R7.1, R8.2, U4.3 (EN)
unnamed: C22.2, L1.1, U4.8 (PH), U15.2
unnamed: C21.1, U4.4 (SS)
unnamed: R10.1, R11.2, U4.5 (VSENSE)
unnamed: C53.2, U5.2 (AVDD), U5.20 (CCFG)
unnamed: R48.2, U5.16 (CBI)
unnamed: R33.1, U5.13 (CHG)
unnamed: R32.1, U5.12 (DSG)
unnamed: R34.1, U5.14 (LD)
unnamed: R47.2, U5.17 (OCDP)
unnamed: R22.1, U5.22 (PRES)
unnamed: Q4.1 (S), Q4.2 (S), Q4.3 (S), R30.2, U5.11 (SRN), U6.2
unnamed: R19.1, R21.2, U5.18 (TS)
unnamed: C50.2, C62.1, R28.2, U5.7 (VC1)
unnamed: C49.2, C50.1, R27.2, U5.6 (VC2)
unnamed: C19.2, C49.1, R26.2, U5.5 (VC3)
unnamed: C19.1, R25.2, U5.3 (VC5), U5.4 (VC4)
unnamed: C51.2, R46.2, U5.8 (VCO)
unnamed: C52.2, R22.2, R36.2, U5.1 (VDD)
unnamed: R21.1, U5.19 (VTB)
unnamed: C38.1, U21.19 (BTST2)
unnamed: C39.2, U21.24 (SDRV)
unnamed: C37.1, L2.2, U21.28 (SW1)
unnamed: C38.2, L2.1, U21.26 (SW2)
P3V3: C9.1, C26.2, H1.2, H3.2, U3.5 (OUT), U7.38 (VIN_3V3)
PMID: C27.1, C28.1, C29.1, C30.1, U21.29 (PMID)
PP5V: C10.1, C17.1, C18.1, C25.1, H7.2, L1.2, R9.2, U3.1 (IN), U3.3 (EN), U7.34 (PP5V), U7.35 (PP5V), U10.1
PPHV: C3.1, C4.1, C5.1, C31.1, C32.1, C33.1, C34.1, C35.1, H6.2, U7.20 (PPHV), U7.21 (PPHV), U7.22 (PPHV), U21.2 (VBUS), U21.3 (VBUS), U21.8 (VAC2), U21.9 (VAC1)
PROG: R14.2, U21.20 (PROG)
STAT: LED1.2 (+), U21.1 (STAT)
SYS: C11.1, C15.1, C16.1, C20.1, C41.2, C42.2, C43.2, C44.2, C45.2, C46.2, H4.2, R7.2, U4.2 (VIN), U21.25 (SYS)
TS: R17.1, R18.2, R20.2, U21.16 (TS)
VBUS: L3.2, U7.23 (VBUS_IN), U7.24 (VBUS_IN), U7.25 (VBUS_IN), U7.32 (VBUS), U7.33 (VBUS)

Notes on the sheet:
Cell Balancing Circuit
Lithium Battery Charger 2/4S
SMD nuts
VOUT = 3.3V, 500mA
XT30PW-F Connector Output to other board
USB-C WITH FUSE,NOISE AND ESD PROTECTION
I2C
Power
I2C1
For maximum charging current
USB-C power delivery (PD) controller
EEPROM
Set Number of Cells 2S - 6.04k 3S - 10.5k 4S - 17.4k
VOUT = 5V, 5A

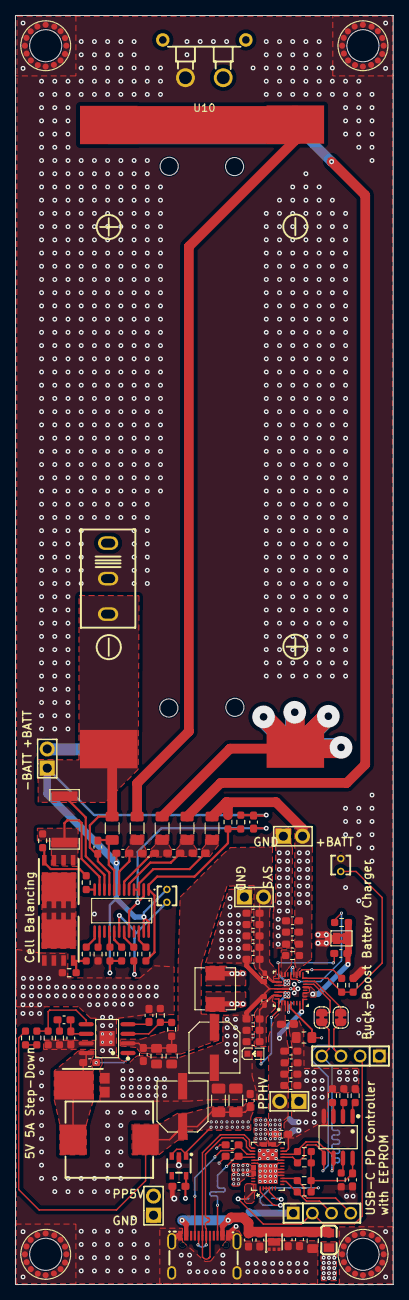
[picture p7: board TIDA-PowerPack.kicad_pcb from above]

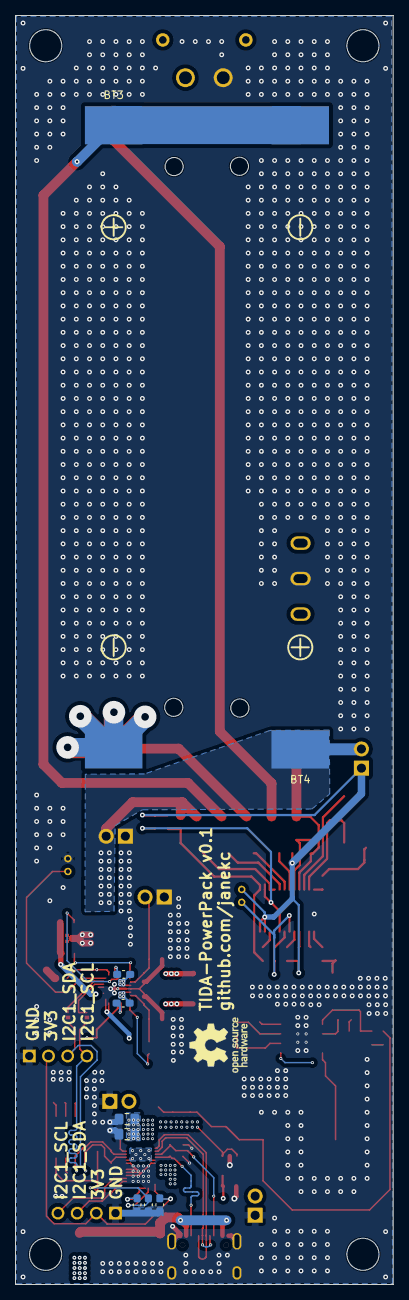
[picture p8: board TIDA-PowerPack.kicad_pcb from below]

Board: 4 copper layers, 50.0 x 168.0 mm, 127 parts (9 on the bottom side), 68 nets.

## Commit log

2024-05-18 export schematics
    [LCSC_AllParts.csv, tida-050047-ledcontroller.kicad_sch]
2024-06-02 update from fiver
    [tida-050047-ledcontroller.kicad_sch]
2024-06-06 update schematics, add cell monitors that switches cells off if something is wrong, started pcb layout
    [tida-050047-ledcontroller.kicad_pcb]
2024-10-10 rearrange charger components
2024-10-11 fix commit
    [tida-050047-ledcontroller.kicad_pcb]
2024-10-12 fix zones with via stiching
    [tida-050047-ledcontroller.kicad_pcb, tida-050047-ledcontroller.kicad_sch]
2025-04-04 add pcb layout using the layout guidelines froms the texas instruments ICs
    [tida-050047-ledcontroller-test-without-smaller.kicad_pcb, tida-050047-ledcontroller.kicad_pcb, tida-050047-ledcontroller.kicad_sch]
2025-04-07 replace battery protection with IC that actually balances the cells
    [tida-050047-ledcontroller.kicad_pcb, tida-050047-ledcontroller.kicad_sch]
2025-04-07 enlarge silkscreen font
    [tida-050047-ledcontroller.kicad_pcb]
2025-04-07 add gerber files
    [TIDA-PowerPack-B_Cu.gbl, TIDA-PowerPack-B_Mask.gbs, TIDA-PowerPack-B_Paste.gbp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]
2025-04-07 ordered prototype
2025-04-08 add 3d models
    [TIDA-PowerPack.kicad_pcb]
2025-04-08 add 3d model
    [TIDA-PowerPack.kicad_pcb]
2025-04-08 replace TPS25750D with TPS25751 chip
    [REF0038A.stp, RQM0029A.stp, TIDA-PowerPack.kicad_pcb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]
